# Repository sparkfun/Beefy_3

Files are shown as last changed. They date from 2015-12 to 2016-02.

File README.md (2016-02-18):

SparkFun FTDI Basic Breakout Board-3.3V
========================================

SparkFun Beefy 3 (3.3V FTDI Breakout)

[*SparkFun Beefy 3 (3.3V FTDI Breakout) (DEV-13746)*](https://www.sparkfun.com/products/13746)

This is a breakout board for the FTDI FT232RL USB to serial IC with integrated 3.3V (up to 600mA) regulator to power your project.
The pinout of this board matches the FTDI cable to work with official Arduino and cloned 3.3V Arduino boards.

Repository Contents
-------------------
* **/Hardware** &mdash; All Eagle design files (.brd, .sch)
* **/Production** &mdash; Test bed files and production panel files

Product Versions
----------------
* 
[This](https://www.sparkfun.com/products/13746) &mdash; Higher power 3.3V FTDI Breakout.
* [DEV-09873](https://www.sparkfun.com/products/9873) &mdash; 3.3V FTDI Basic Breakout.
* [DEV-09716](https://www.sparkfun.com/products/9716) &mdash; 5V FTDI Basic Breakout

License Information
-------------------
The hardware is released under [Creative Commons ShareAlike 4.0 International](https://creativecommons.org/licenses/by-sa/4.0/).

Distributed as-is; no warranty is given.

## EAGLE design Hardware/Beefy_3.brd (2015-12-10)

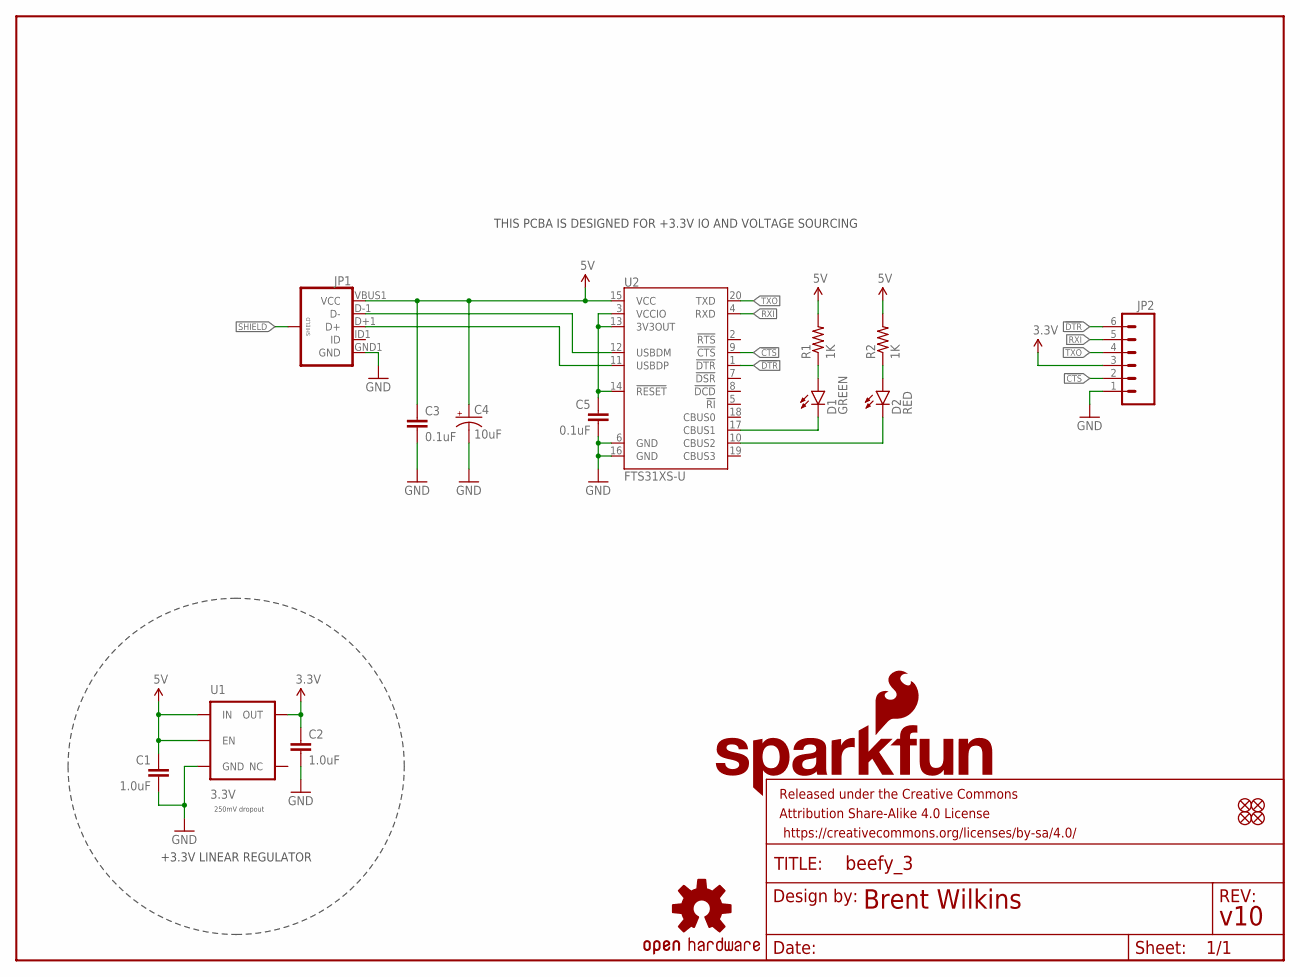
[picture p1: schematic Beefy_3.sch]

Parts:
C1, C2: 1.0uF; 0603-CAP
C3, C5: 0.1uF; 0603-CAP
C4: 10uF; EIA3216
D1: GREEN; LED-0603
D2: RED; LED-0603
FRAME1: FRAME-LETTER; CREATIVE_COMMONS
JP1: USB_MICROB_PLUGCONN-11752; USB-B-MICRO-SMD_V03
JP2: M06SMD-FEMALE-V2; 1X06-SMD-FEMALE-V2
JP3, JP4, JP5, JP6: FIDUCIAL1X2; FIDUCIAL-1X2
LOGO1: OSHW-LOGOS; OSHW-LOGO-S
LOGO2: SFE_LOGO_NAME.1_INCH; SFE_LOGO_NAME_.1
LOGO3: SFE_LOGO_FLAME.1_INCH; SFE_LOGO_FLAME_.1
R1, R2: 1K; 0603-RES
U1: 3.3V; SOT23-5
U2: FTS31XS-U; SSOP20_L

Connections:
3V3: C2.1, JP2.3, U1.5 (OUT)
3V3LC: C5.1, U2.3 (VCCIO), U2.13 (3V3OUT), U2.14 (!RESET)
5V: C1.1, C3.1, C4.A (+), JP1.VBUS1 (VCC), R1.2, R2.2, U1.1 (IN), U1.3 (EN), U2.15 (VCC)
!CTS: JP2.2, U2.9 (!CTS)
!DTR: JP2.6, U2.1 (!DTR)
GND: C1.2, C2.2, C3.2, C4.C (-), C5.2, JP1.GND1 (GND), JP2.1, U1.2 (GND), U2.6 (GND), U2.16 (GND)
unnamed: D2.A, R2.1
unnamed: D1.A, R1.1
RXI: JP2.5, U2.4 (RXD)
RXLED: D1.C, U2.17 (CBUS1)
SHIELD: JP1.SHIELD1 (SHIELD), JP1.SHIELD2 (SHIELD), JP1.SHIELD3 (SHIELD)
TXLED: D2.C, U2.10 (CBUS2)
TXO: JP2.4, U2.20 (TXD)
USB_D+: JP1.D+1 (D+), U2.11 (USBDP)
USB_D-: JP1.D-1 (D-), U2.12 (USBDM)

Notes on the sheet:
+3.3V LINEAR REGULATOR
250mV dropout
THIS PCBA IS DESIGNED FOR +3.3V IO AND VOLTAGE SOURCING

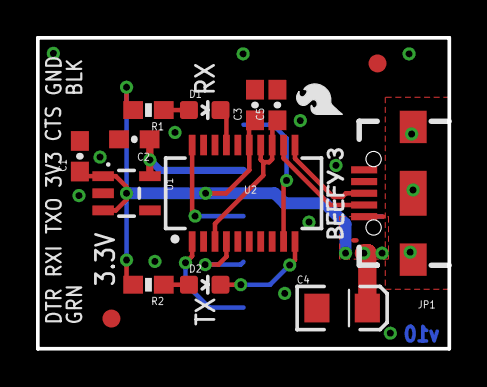
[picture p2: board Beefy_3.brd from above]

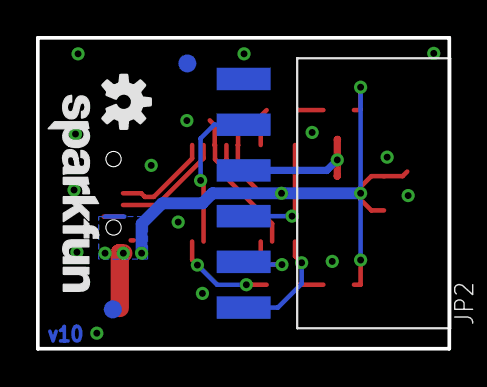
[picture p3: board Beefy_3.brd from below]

Board: 2 copper layers, 22.9 x 17.3 mm, 21 parts (5 on the bottom side), 15 nets.

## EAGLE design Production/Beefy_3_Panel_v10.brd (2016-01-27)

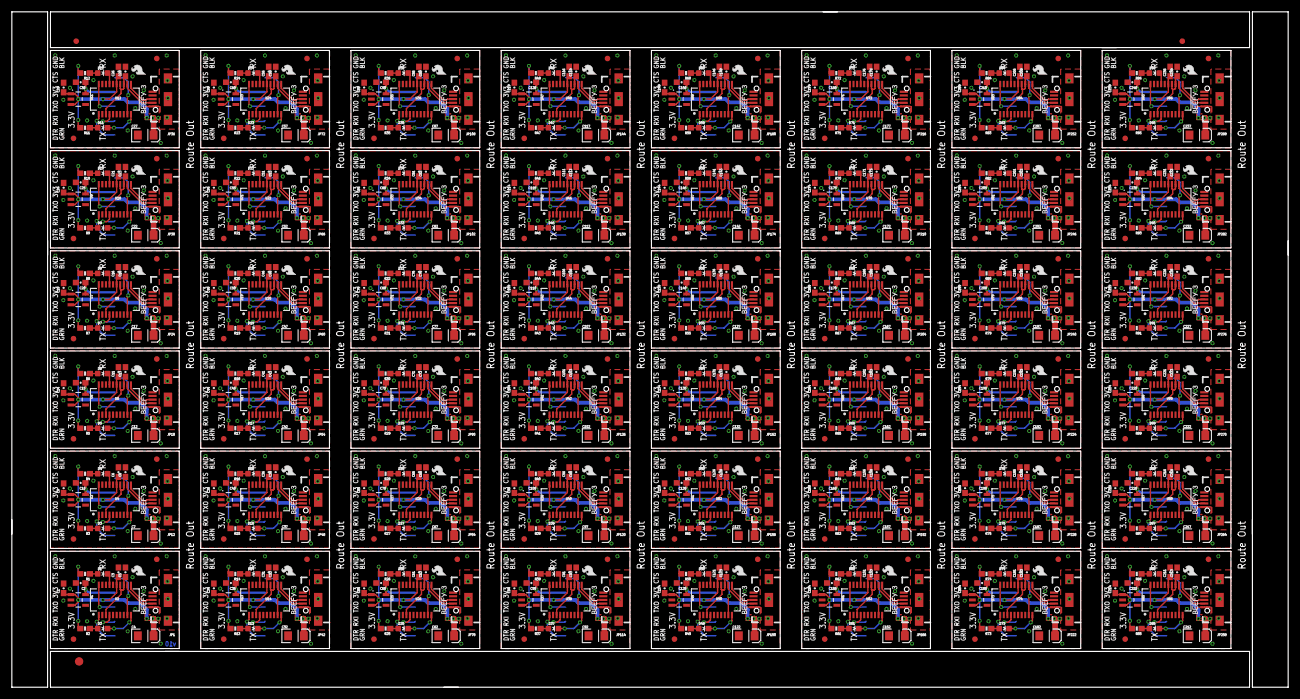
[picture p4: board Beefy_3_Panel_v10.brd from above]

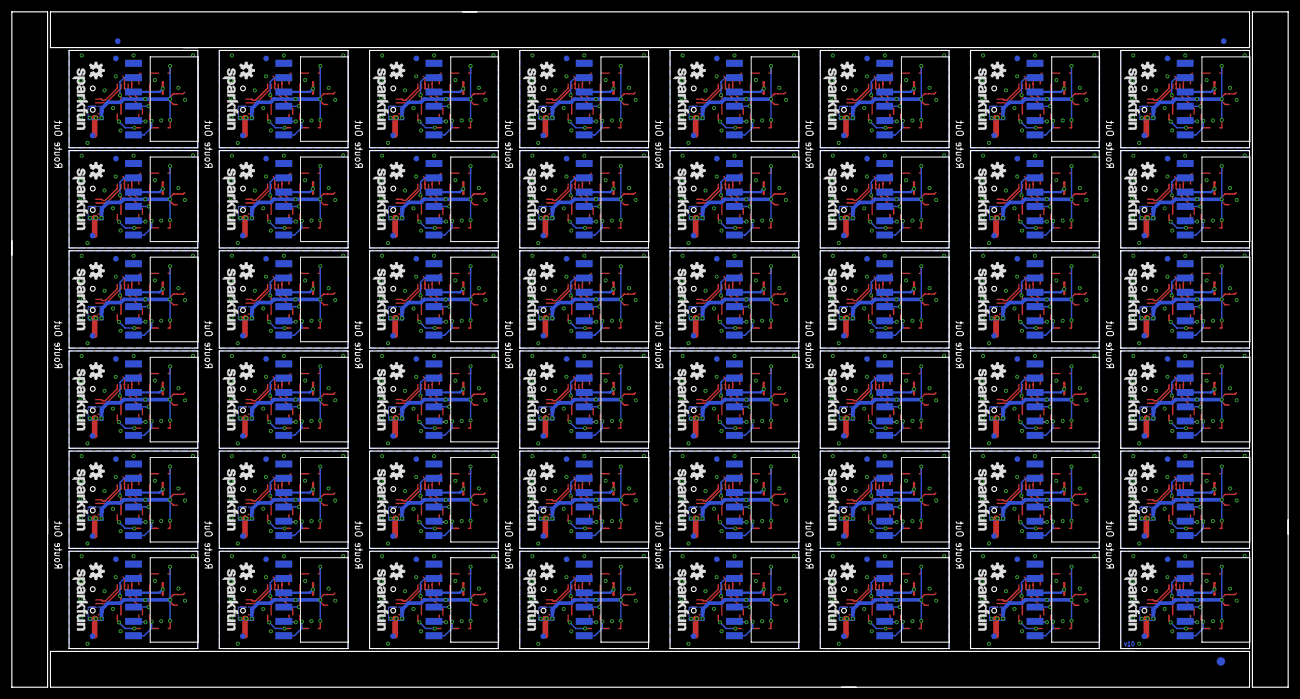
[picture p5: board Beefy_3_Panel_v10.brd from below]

Board: 2 copper layers, 226.6 x 119.9 mm, 966 parts (243 on the bottom side), 720 nets.

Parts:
C1, C2, C9, C10, C14, C15, C19, C20, C24, C25, C29, C30, C34, C35, C39, C40, C44, C45, C49, C50, C54, C55, C59, C60, C64, C65, C69, C70, C74, C75, C79, C80, C84, C85, C89, C90, C94, C95, C99, C100, C104, C105, C109, C110, C114, C115, C119, C120, C124, C125, C129, C130, C134, C135, C139, C140, C144, C145, C149, C150, C154, C155, C159, C160, C164, C165, C169, C170, C174, C175, C179, C180, C184, C185, C189, C190, C194, C195, C199, C200, C204, C205, C209, C210, C214, C215, C219, C220, C224, C225, C229, C230, C234, C235, C239, C240: 1.0uF; 0603-CAP
C3, C5, C6, C8, C11, C13, C16, C18, C21, C23, C26, C28, C31, C33, C36, C38, C41, C43, C46, C48, C51, C53, C56, C58, C61, C63, C66, C68, C71, C73, C76, C78, C81, C83, C86, C88, C91, C93, C96, C98, C101, C103, C106, C108, C111, C113, C116, C118, C121, C123, C126, C128, C131, C133, C136, C138, C141, C143, C146, C148, C151, C153, C156, C158, C161, C163, C166, C168, C171, C173, C176, C178, C181, C183, C186, C188, C191, C193, C196, C198, C201, C203, C206, C208, C211, C213, C216, C218, C221, C223, C226, C228, C231, C233, C236, C238: 0.1uF; 0603-CAP
C4, C7, C12, C17, C22, C27, C32, C37, C42, C47, C52, C57, C62, C67, C72, C77, C82, C87, C92, C97, C102, C107, C112, C117, C122, C127, C132, C137, C142, C147, C152, C157, C162, C167, C172, C177, C182, C187, C192, C197, C202, C207, C212, C217, C222, C227, C232, C237: 10uF; EIA3216
D1, D4, D6, D8, D10, D12, D14, D16, D18, D20, D22, D24, D26, D28, D30, D32, D34, D36, D38, D40, D42, D44, D46, D48, D50, D52, D54, D56, D58, D60, D62, D64, D66, D68, D70, D72, D74, D76, D78, D80, D82, D84, D86, D88, D90, D92, D94, D96: GREEN; LED-0603
D2, D3, D5, D7, D9, D11, D13, D15, D17, D19, D21, D23, D25, D27, D29, D31, D33, D35, D37, D39, D41, D43, D45, D47, D49, D51, D53, D55, D57, D59, D61, D63, D65, D67, D69, D71, D73, D75, D77, D79, D81, D83, D85, D87, D89, D91, D93, D95: RED; LED-0603
E$1, E$2: FIDUCIAL-1.5X3
E$3, E$4, E$7, E$8: FIDUCIAL-1X2
JP1, JP12, JP18, JP24, JP30, JP36, JP42, JP48, JP54, JP60, JP66, JP72, JP78, JP84, JP90, JP96, JP102, JP108, JP114, JP120, JP126, JP132, JP138, JP144, JP150, JP156, JP162, JP168, JP174, JP180, JP186, JP192, JP198, JP204, JP210, JP216, JP222, JP228, JP234, JP240, JP246, JP252, JP258, JP264, JP270, JP276, JP282, JP288: USB-B-MICRO-SMD_V03
JP2, JP7, JP13, JP19, JP25, JP31, JP37, JP43, JP49, JP55, JP61, JP67, JP73, JP79, JP85, JP91, JP97, JP103, JP109, JP115, JP121, JP127, JP133, JP139, JP145, JP151, JP157, JP163, JP169, JP175, JP181, JP187, JP193, JP199, JP205, JP211, JP217, JP223, JP229, JP235, JP241, JP247, JP253, JP259, JP265, JP271, JP277, JP283: 1X06-SMD-FEMALE-V2
JP3, JP4, JP5, JP6, JP8, JP9, JP10, JP11, JP14, JP15, JP16, JP17, JP20, JP21, JP22, JP23, JP26, JP27, JP28, JP29, JP32, JP33, JP34, JP35, JP38, JP39, JP40, JP41, JP44, JP45, JP46, JP47, JP50, JP51, JP52, JP53, JP56, JP57, JP58, JP59, JP62, JP63, JP64, JP65, JP68, JP69, JP70, JP71, JP74, JP75, JP76, JP77, JP80, JP81, JP82, JP83, JP86, JP87, JP88, JP89, JP92, JP93, JP94, JP95, JP98, JP99, JP100, JP101, JP104, JP105, JP106, JP107, JP110, JP111, JP112, JP113, JP116, JP117, JP118, JP119, JP122, JP123, JP124, JP125, JP128, JP129, JP130, JP131, JP134, JP135, JP136, JP137, JP140, JP141, JP142, JP143, JP146, JP147, JP148, JP149, JP152, JP153, JP154, JP155, JP158, JP159, JP160, JP161, JP164, JP165, JP166, JP167, JP170, JP171, JP172, JP173, JP176, JP177, JP178, JP179, JP182, JP183, JP184, JP185, JP188, JP189, JP190, JP191, JP194, JP195, JP196, JP197, JP200, JP201, JP202, JP203, JP206, JP207, JP208, JP209, JP212, JP213, JP214, JP215, JP218, JP219, JP220, JP221, JP224, JP225, JP226, JP227, JP230, JP231, JP232, JP233, JP236, JP237, JP238, JP239, JP242, JP243, JP244, JP245, JP248, JP249, JP250, JP251, JP254, JP255, JP256, JP257, JP260, JP261, JP262, JP263, JP266, JP267, JP268, JP269, JP272, JP273, JP274, JP275, JP278, JP279, JP280, JP281, JP284, JP285, JP286, JP287: FIDUCIAL1X2; FIDUCIAL-1X2
LOGO1, LOGO5, LOGO8, LOGO11, LOGO14, LOGO17, LOGO20, LOGO23, LOGO26, LOGO29, LOGO32, LOGO35, LOGO38, LOGO41, LOGO44, LOGO47, LOGO50, LOGO53, LOGO56, LOGO59, LOGO62, LOGO65, LOGO68, LOGO71, LOGO74, LOGO77, LOGO80, LOGO83, LOGO86, LOGO89, LOGO92, LOGO95, LOGO98, LOGO101, LOGO104, LOGO107, LOGO110, LOGO113, LOGO116, LOGO119, LOGO122, LOGO125, LOGO128, LOGO131, LOGO134, LOGO137, LOGO140, LOGO143: OSHW-LOGOS; OSHW-LOGO-S
LOGO2, LOGO4, LOGO7, LOGO10, LOGO13, LOGO16, LOGO19, LOGO22, LOGO25, LOGO28, LOGO31, LOGO34, LOGO37, LOGO40, LOGO43, LOGO46, LOGO49, LOGO52, LOGO55, LOGO58, LOGO61, LOGO64, LOGO67, LOGO70, LOGO73, LOGO76, LOGO79, LOGO82, LOGO85, LOGO88, LOGO91, LOGO94, LOGO97, LOGO100, LOGO103, LOGO106, LOGO109, LOGO112, LOGO115, LOGO118, LOGO121, LOGO124, LOGO127, LOGO130, LOGO133, LOGO136, LOGO139, LOGO142: SFE_LOGO_NAME.1_INCH; SFE_LOGO_NAME_.1
LOGO3, LOGO6, LOGO9, LOGO12, LOGO15, LOGO18, LOGO21, LOGO24, LOGO27, LOGO30, LOGO33, LOGO36, LOGO39, LOGO42, LOGO45, LOGO48, LOGO51, LOGO54, LOGO57, LOGO60, LOGO63, LOGO66, LOGO69, LOGO72, LOGO75, LOGO78, LOGO81, LOGO84, LOGO87, LOGO90, LOGO93, LOGO96, LOGO99, LOGO102, LOGO105, LOGO108, LOGO111, LOGO114, LOGO117, LOGO120, LOGO123, LOGO126, LOGO129, LOGO132, LOGO135, LOGO138, LOGO141, LOGO144: SFE_LOGO_FLAME.1_INCH; SFE_LOGO_FLAME_.1
R1, R2, R3, R4, R5, R6, R7, R8, R9, R10, R11, R12, R13, R14, R15, R16, R17, R18, R19, R20, R21, R22, R23, R24, R25, R26, R27, R28, R29, R30, R31, R32, R33, R34, R35, R36, R37, R38, R39, R40, R41, R42, R43, R44, R45, R46, R47, R48, R49, R50, R51, R52, R53, R54, R55, R56, R57, R58, R59, R60, R61, R62, R63, R64, R65, R66, R67, R68, R69, R70, R71, R72, R73, R74, R75, R76, R77, R78, R79, R80, R81, R82, R83, R84, R85, R86, R87, R88, R89, R90, R91, R92, R93, R94, R95, R96: 1K; 0603-RES
U1, U3, U5, U7, U9, U11, U13, U15, U17, U19, U21, U23, U25, U27, U29, U31, U33, U35, U37, U39, U41, U43, U45, U47, U49, U51, U53, U55, U57, U59, U61, U63, U65, U67, U69, U71, U73, U75, U77, U79, U81, U83, U85, U87, U89, U91, U93, U95: 3.3V; SOT23-5
U2, U4, U6, U8, U10, U12, U14, U16, U18, U20, U22, U24, U26, U28, U30, U32, U34, U36, U38, U40, U42, U44, U46, U48, U50, U52, U54, U56, U58, U60, U62, U64, U66, U68, U70, U72, U74, U76, U78, U80, U82, U84, U86, U88, U90, U92, U94, U96: FTS31XS-U; SSOP20_L

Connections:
3V1: C10.1, JP7.3, U3.5
3V2: C15.1, JP13.3, U5.5
3V3: C2.1, JP2.3, U1.5
3V3LC: C5.1, U2.3, U2.13, U2.14
3V3LC1: C8.1, U4.3, U4.13, U4.14
3V3LC2: C13.1, U6.3, U6.13, U6.14
3V3LC3: C18.1, U8.3, U8.13, U8.14
3V3LC4: C23.1, U10.3, U10.13, U10.14
3V3LC5: C28.1, U12.3, U12.13, U12.14
3V3LC6: C33.1, U14.3, U14.13, U14.14
3V3LC7: C38.1, U16.3, U16.13, U16.14
3V3LC8: C43.1, U18.3, U18.13, U18.14
3V3LC9: C48.1, U20.3, U20.13, U20.14
3V3LC10: C53.1, U22.3, U22.13, U22.14
3V3LC11: C58.1, U24.3, U24.13, U24.14
3V3LC12: C63.1, U26.3, U26.13, U26.14
3V3LC13: C68.1, U28.3, U28.13, U28.14
3V3LC14: C73.1, U30.3, U30.13, U30.14
3V3LC15: C78.1, U32.3, U32.13, U32.14
3V3LC16: C83.1, U34.3, U34.13, U34.14
3V3LC17: C88.1, U36.3, U36.13, U36.14
3V3LC18: C93.1, U38.3, U38.13, U38.14
3V3LC19: C98.1, U40.3, U40.13, U40.14
3V3LC20: C103.1, U42.3, U42.13, U42.14
3V3LC21: C108.1, U44.3, U44.13, U44.14
3V3LC22: C113.1, U46.3, U46.13, U46.14
3V3LC23: C118.1, U48.3, U48.13, U48.14
3V3LC24: C123.1, U50.3, U50.13, U50.14
3V3LC25: C128.1, U52.3, U52.13, U52.14
3V3LC26: C133.1, U54.3, U54.13, U54.14
3V3LC27: C138.1, U56.3, U56.13, U56.14
3V3LC28: C143.1, U58.3, U58.13, U58.14
3V3LC29: C148.1, U60.3, U60.13, U60.14
3V3LC30: C153.1, U62.3, U62.13, U62.14
3V3LC31: C158.1, U64.3, U64.13, U64.14
3V3LC32: C163.1, U66.3, U66.13, U66.14
3V3LC33: C168.1, U68.3, U68.13, U68.14
3V3LC34: C173.1, U70.3, U70.13, U70.14
3V3LC35: C178.1, U72.3, U72.13, U72.14
3V3LC36: C183.1, U74.3, U74.13, U74.14
3V3LC37: C188.1, U76.3, U76.13, U76.14
3V3LC38: C193.1, U78.3, U78.13, U78.14
3V3LC39: C198.1, U80.3, U80.13, U80.14
3V3LC40: C203.1, U82.3, U82.13, U82.14
3V3LC41: C208.1, U84.3, U84.13, U84.14
3V3LC42: C213.1, U86.3, U86.13, U86.14
3V3LC43: C218.1, U88.3, U88.13, U88.14
3V3LC44: C223.1, U90.3, U90.13, U90.14
3V3LC45: C228.1, U92.3, U92.13, U92.14
3V3LC46: C233.1, U94.3, U94.13, U94.14
3V3LC47: C238.1, U96.3, U96.13, U96.14
3V4: C20.1, JP19.3, U7.5
3V5: C25.1, JP25.3, U9.5
3V6: C30.1, JP31.3, U11.5
3V7: C35.1, JP37.3, U13.5
3V8: C40.1, JP43.3, U15.5
3V9: C45.1, JP49.3, U17.5
3V10: C50.1, JP55.3, U19.5
3V11: C55.1, JP61.3, U21.5
3V12: C60.1, JP67.3, U23.5
3V13: C65.1, JP73.3, U25.5
3V14: C70.1, JP79.3, U27.5
3V15: C75.1, JP85.3, U29.5
3V16: C80.1, JP91.3, U31.5
3V17: C85.1, JP97.3, U33.5
3V18: C90.1, JP103.3, U35.5
3V19: C95.1, JP109.3, U37.5
3V20: C100.1, JP115.3, U39.5
3V21: C105.1, JP121.3, U41.5
3V22: C110.1, JP127.3, U43.5
3V23: C115.1, JP133.3, U45.5
3V24: C120.1, JP139.3, U47.5
3V25: C125.1, JP145.3, U49.5
3V26: C130.1, JP151.3, U51.5
3V27: C135.1, JP157.3, U53.5
3V28: C140.1, JP163.3, U55.5
3V29: C145.1, JP169.3, U57.5
3V30: C150.1, JP175.3, U59.5
3V31: C155.1, JP181.3, U61.5
3V32: C160.1, JP187.3, U63.5
3V33: C165.1, JP193.3, U65.5
3V34: C170.1, JP199.3, U67.5
3V35: C175.1, JP205.3, U69.5
3V36: C180.1, JP211.3, U71.5
3V37: C185.1, JP217.3, U73.5
3V38: C190.1, JP223.3, U75.5
3V39: C195.1, JP229.3, U77.5
3V40: C200.1, JP235.3, U79.5
3V41: C205.1, JP241.3, U81.5
3V42: C210.1, JP247.3, U83.5
3V43: C215.1, JP253.3, U85.5
3V44: C220.1, JP259.3, U87.5
3V45: C225.1, JP265.3, U89.5
3V46: C230.1, JP271.3, U91.5
3V47: C235.1, JP277.3, U93.5
3V48: C240.1, JP283.3, U95.5
5V: C1.1, C3.1, C4.A, JP1.VBUS1, R1.2, R2.2, U1.1, U1.3, U2.15
5V1: C6.1, C7.A, C9.1, JP12.VBUS1, R3.2, R4.2, U3.1, U3.3, U4.15
5V2: C11.1, C12.A, C14.1, JP18.VBUS1, R5.2, R6.2, U5.1, U5.3, U6.15
5V3: C16.1, C17.A, C19.1, JP24.VBUS1, R7.2, R8.2, U7.1, U7.3, U8.15
5V4: C21.1, C22.A, C24.1, JP30.VBUS1, R9.2, R10.2, U9.1, U9.3, U10.15
5V5: C26.1, C27.A, C29.1, JP36.VBUS1, R11.2, R12.2, U11.1, U11.3, U12.15
5V6: C31.1, C32.A, C34.1, JP42.VBUS1, R13.2, R14.2, U13.1, U13.3, U14.15
5V7: C36.1, C37.A, C39.1, JP48.VBUS1, R15.2, R16.2, U15.1, U15.3, U16.15
5V8: C41.1, C42.A, C44.1, JP54.VBUS1, R17.2, R18.2, U17.1, U17.3, U18.15
5V9: C46.1, C47.A, C49.1, JP60.VBUS1, R19.2, R20.2, U19.1, U19.3, U20.15
5V10: C51.1, C52.A, C54.1, JP66.VBUS1, R21.2, R22.2, U21.1, U21.3, U22.15
5V11: C56.1, C57.A, C59.1, JP72.VBUS1, R23.2, R24.2, U23.1, U23.3, U24.15
5V12: C61.1, C62.A, C64.1, JP78.VBUS1, R25.2, R26.2, U25.1, U25.3, U26.15
5V13: C66.1, C67.A, C69.1, JP84.VBUS1, R27.2, R28.2, U27.1, U27.3, U28.15
5V14: C71.1, C72.A, C74.1, JP90.VBUS1, R29.2, R30.2, U29.1, U29.3, U30.15
5V15: C76.1, C77.A, C79.1, JP96.VBUS1, R31.2, R32.2, U31.1, U31.3, U32.15
5V16: C81.1, C82.A, C84.1, JP102.VBUS1, R33.2, R34.2, U33.1, U33.3, U34.15
5V17: C86.1, C87.A, C89.1, JP108.VBUS1, R35.2, R36.2, U35.1, U35.3, U36.15
5V18: C91.1, C92.A, C94.1, JP114.VBUS1, R37.2, R38.2, U37.1, U37.3, U38.15
5V19: C96.1, C97.A, C99.1, JP120.VBUS1, R39.2, R40.2, U39.1, U39.3, U40.15
5V20: C101.1, C102.A, C104.1, JP126.VBUS1, R41.2, R42.2, U41.1, U41.3, U42.15
5V21: C106.1, C107.A, C109.1, JP132.VBUS1, R43.2, R44.2, U43.1, U43.3, U44.15
5V22: C111.1, C112.A, C114.1, JP138.VBUS1, R45.2, R46.2, U45.1, U45.3, U46.15
5V23: C116.1, C117.A, C119.1, JP144.VBUS1, R47.2, R48.2, U47.1, U47.3, U48.15
5V24: C121.1, C122.A, C124.1, JP150.VBUS1, R49.2, R50.2, U49.1, U49.3, U50.15
5V25: C126.1, C127.A, C129.1, JP156.VBUS1, R51.2, R52.2, U51.1, U51.3, U52.15
5V26: C131.1, C132.A, C134.1, JP162.VBUS1, R53.2, R54.2, U53.1, U53.3, U54.15
5V27: C136.1, C137.A, C139.1, JP168.VBUS1, R55.2, R56.2, U55.1, U55.3, U56.15
5V28: C141.1, C142.A, C144.1, JP174.VBUS1, R57.2, R58.2, U57.1, U57.3, U58.15
5V29: C146.1, C147.A, C149.1, JP180.VBUS1, R59.2, R60.2, U59.1, U59.3, U60.15
5V30: C151.1, C152.A, C154.1, JP186.VBUS1, R61.2, R62.2, U61.1, U61.3, U62.15
5V31: C156.1, C157.A, C159.1, JP192.VBUS1, R63.2, R64.2, U63.1, U63.3, U64.15
5V32: C161.1, C162.A, C164.1, JP198.VBUS1, R65.2, R66.2, U65.1, U65.3, U66.15
5V33: C166.1, C167.A, C169.1, JP204.VBUS1, R67.2, R68.2, U67.1, U67.3, U68.15
5V34: C171.1, C172.A, C174.1, JP210.VBUS1, R69.2, R70.2, U69.1, U69.3, U70.15
5V35: C176.1, C177.A, C179.1, JP216.VBUS1, R71.2, R72.2, U71.1, U71.3, U72.15
5V36: C181.1, C182.A, C184.1, JP222.VBUS1, R73.2, R74.2, U73.1, U73.3, U74.15
5V37: C186.1, C187.A, C189.1, JP228.VBUS1, R75.2, R76.2, U75.1, U75.3, U76.15
5V38: C191.1, C192.A, C194.1, JP234.VBUS1, R77.2, R78.2, U77.1, U77.3, U78.15
5V39: C196.1, C197.A, C199.1, JP240.VBUS1, R79.2, R80.2, U79.1, U79.3, U80.15
5V40: C201.1, C202.A, C204.1, JP246.VBUS1, R81.2, R82.2, U81.1, U81.3, U82.15
5V41: C206.1, C207.A, C209.1, JP252.VBUS1, R83.2, R84.2, U83.1, U83.3, U84.15
5V42: C211.1, C212.A, C214.1, JP258.VBUS1, R85.2, R86.2, U85.1, U85.3, U86.15
5V43: C216.1, C217.A, C219.1, JP264.VBUS1, R87.2, R88.2, U87.1, U87.3, U88.15
5V44: C221.1, C222.A, C224.1, JP270.VBUS1, R89.2, R90.2, U89.1, U89.3, U90.15
5V45: C226.1, C227.A, C229.1, JP276.VBUS1, R91.2, R92.2, U91.1, U91.3, U92.15
5V46: C231.1, C232.A, C234.1, JP282.VBUS1, R93.2, R94.2, U93.1, U93.3, U94.15
5V47: C236.1, C237.A, C239.1, JP288.VBUS1, R95.2, R96.2, U95.1, U95.3, U96.15
!CTS: JP2.2, U2.9
!CTS1: JP7.2, U4.9
!CTS2: JP13.2, U6.9
!CTS3: JP19.2, U8.9
!CTS4: JP25.2, U10.9
!CTS5: JP31.2, U12.9
!CTS6: JP37.2, U14.9
!CTS7: JP43.2, U16.9
!CTS8: JP49.2, U18.9
!CTS9: JP55.2, U20.9
!CTS10: JP61.2, U22.9
!CTS11: JP67.2, U24.9
!CTS12: JP73.2, U26.9
!CTS13: JP79.2, U28.9
!CTS14: JP85.2, U30.9
!CTS15: JP91.2, U32.9
!CTS16: JP97.2, U34.9
!CTS17: JP103.2, U36.9
!CTS18: JP109.2, U38.9
!CTS19: JP115.2, U40.9
!CTS20: JP121.2, U42.9
!CTS21: JP127.2, U44.9
!CTS22: JP133.2, U46.9
!CTS23: JP139.2, U48.9
!CTS24: JP145.2, U50.9
!CTS25: JP151.2, U52.9
!CTS26: JP157.2, U54.9
!CTS27: JP163.2, U56.9
!CTS28: JP169.2, U58.9
!CTS29: JP175.2, U60.9
!CTS30: JP181.2, U62.9
!CTS31: JP187.2, U64.9
!CTS32: JP193.2, U66.9
!CTS33: JP199.2, U68.9
!CTS34: JP205.2, U70.9
!CTS35: JP211.2, U72.9
!CTS36: JP217.2, U74.9
!CTS37: JP223.2, U76.9
!CTS38: JP229.2, U78.9
!CTS39: JP235.2, U80.9
!CTS40: JP241.2, U82.9
!CTS41: JP247.2, U84.9
!CTS42: JP253.2, U86.9
!CTS43: JP259.2, U88.9
!CTS44: JP265.2, U90.9
!CTS45: JP271.2, U92.9
!CTS46: JP277.2, U94.9
!CTS47: JP283.2, U96.9
!DTR: JP2.6, U2.1
!DTR1: JP7.6, U4.1
!DTR2: JP13.6, U6.1
!DTR3: JP19.6, U8.1
!DTR4: JP25.6, U10.1
!DTR5: JP31.6, U12.1
!DTR6: JP37.6, U14.1
!DTR7: JP43.6, U16.1
!DTR8: JP49.6, U18.1
!DTR9: JP55.6, U20.1
!DTR10: JP61.6, U22.1
!DTR11: JP67.6, U24.1
!DTR12: JP73.6, U26.1
!DTR13: JP79.6, U28.1
!DTR14: JP85.6, U30.1
!DTR15: JP91.6, U32.1
!DTR16: JP97.6, U34.1
!DTR17: JP103.6, U36.1
!DTR18: JP109.6, U38.1
!DTR19: JP115.6, U40.1
!DTR20: JP121.6, U42.1
!DTR21: JP127.6, U44.1
!DTR22: JP133.6, U46.1
!DTR23: JP139.6, U48.1
!DTR24: JP145.6, U50.1
!DTR25: JP151.6, U52.1
!DTR26: JP157.6, U54.1
!DTR27: JP163.6, U56.1
!DTR28: JP169.6, U58.1
!DTR29: JP175.6, U60.1
!DTR30: JP181.6, U62.1
!DTR31: JP187.6, U64.1
!DTR32: JP193.6, U66.1
!DTR33: JP199.6, U68.1
!DTR34: JP205.6, U70.1
!DTR35: JP211.6, U72.1
!DTR36: JP217.6, U74.1
!DTR37: JP223.6, U76.1
!DTR38: JP229.6, U78.1
!DTR39: JP235.6, U80.1
!DTR40: JP241.6, U82.1
!DTR41: JP247.6, U84.1
!DTR42: JP253.6, U86.1
!DTR43: JP259.6, U88.1
!DTR44: JP265.6, U90.1
!DTR45: JP271.6, U92.1
!DTR46: JP277.6, U94.1
!DTR47: JP283.6, U96.1
GND: C1.2, C2.2, C3.2, C4.C, C5.2, JP1.GND1, JP2.1, U1.2, U2.6, U2.16
GND1: C6.2, C7.C, C8.2, C9.2, C10.2, JP7.1, JP12.GND1, U3.2, U4.6, U4.16
GND2: C11.2, C12.C, C13.2, C14.2, C15.2, JP13.1, JP18.GND1, U5.2, U6.6, U6.16
GND3: C16.2, C17.C, C18.2, C19.2, C20.2, JP19.1, JP24.GND1, U7.2, U8.6, U8.16
GND4: C21.2, C22.C, C23.2, C24.2, C25.2, JP25.1, JP30.GND1, U9.2, U10.6, U10.16
GND5: C26.2, C27.C, C28.2, C29.2, C30.2, JP31.1, JP36.GND1, U11.2, U12.6, U12.16
GND6: C31.2, C32.C, C33.2, C34.2, C35.2, JP37.1, JP42.GND1, U13.2, U14.6, U14.16
GND7: C36.2, C37.C, C38.2, C39.2, C40.2, JP43.1, JP48.GND1, U15.2, U16.6, U16.16
GND8: C41.2, C42.C, C43.2, C44.2, C45.2, JP49.1, JP54.GND1, U17.2, U18.6, U18.16
GND9: C46.2, C47.C, C48.2, C49.2, C50.2, JP55.1, JP60.GND1, U19.2, U20.6, U20.16
GND10: C51.2, C52.C, C53.2, C54.2, C55.2, JP61.1, JP66.GND1, U21.2, U22.6, U22.16
GND11: C56.2, C57.C, C58.2, C59.2, C60.2, JP67.1, JP72.GND1, U23.2, U24.6, U24.16
GND12: C61.2, C62.C, C63.2, C64.2, C65.2, JP73.1, JP78.GND1, U25.2, U26.6, U26.16
GND13: C66.2, C67.C, C68.2, C69.2, C70.2, JP79.1, JP84.GND1, U27.2, U28.6, U28.16
GND14: C71.2, C72.C, C73.2, C74.2, C75.2, JP85.1, JP90.GND1, U29.2, U30.6, U30.16
GND15: C76.2, C77.C, C78.2, C79.2, C80.2, JP91.1, JP96.GND1, U31.2, U32.6, U32.16
GND16: C81.2, C82.C, C83.2, C84.2, C85.2, JP97.1, JP102.GND1, U33.2, U34.6, U34.16
GND17: C86.2, C87.C, C88.2, C89.2, C90.2, JP103.1, JP108.GND1, U35.2, U36.6, U36.16
GND18: C91.2, C92.C, C93.2, C94.2, C95.2, JP109.1, JP114.GND1, U37.2, U38.6, U38.16
GND19: C96.2, C97.C, C98.2, C99.2, C100.2, JP115.1, JP120.GND1, U39.2, U40.6, U40.16
GND20: C101.2, C102.C, C103.2, C104.2, C105.2, JP121.1, JP126.GND1, U41.2, U42.6, U42.16
GND21: C106.2, C107.C, C108.2, C109.2, C110.2, JP127.1, JP132.GND1, U43.2, U44.6, U44.16
GND22: C111.2, C112.C, C113.2, C114.2, C115.2, JP133.1, JP138.GND1, U45.2, U46.6, U46.16
GND23: C116.2, C117.C, C118.2, C119.2, C120.2, JP139.1, JP144.GND1, U47.2, U48.6, U48.16
GND24: C121.2, C122.C, C123.2, C124.2, C125.2, JP145.1, JP150.GND1, U49.2, U50.6, U50.16
GND25: C126.2, C127.C, C128.2, C129.2, C130.2, JP151.1, JP156.GND1, U51.2, U52.6, U52.16
GND26: C131.2, C132.C, C133.2, C134.2, C135.2, JP157.1, JP162.GND1, U53.2, U54.6, U54.16
GND27: C136.2, C137.C, C138.2, C139.2, C140.2, JP163.1, JP168.GND1, U55.2, U56.6, U56.16
GND28: C141.2, C142.C, C143.2, C144.2, C145.2, JP169.1, JP174.GND1, U57.2, U58.6, U58.16
GND29: C146.2, C147.C, C148.2, C149.2, C150.2, JP175.1, JP180.GND1, U59.2, U60.6, U60.16
GND30: C151.2, C152.C, C153.2, C154.2, C155.2, JP181.1, JP186.GND1, U61.2, U62.6, U62.16
GND31: C156.2, C157.C, C158.2, C159.2, C160.2, JP187.1, JP192.GND1, U63.2, U64.6, U64.16
GND32: C161.2, C162.C, C163.2, C164.2, C165.2, JP193.1, JP198.GND1, U65.2, U66.6, U66.16
GND33: C166.2, C167.C, C168.2, C169.2, C170.2, JP199.1, JP204.GND1, U67.2, U68.6, U68.16
GND34: C171.2, C172.C, C173.2, C174.2, C175.2, JP205.1, JP210.GND1, U69.2, U70.6, U70.16
GND35: C176.2, C177.C, C178.2, C179.2, C180.2, JP211.1, JP216.GND1, U71.2, U72.6, U72.16
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

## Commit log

2015-10-13 Improved high-speed differential routing
    [Beefy_3.brd]
2015-10-13 Added PROD_IDs to library parts and updated them
    [Beefy_3.brd, Beefy_3.sch]
2015-10-19 First pass at using micro B & FT231X
    [Beefy_3.brd, Beefy_3.sch]
2015-10-21 New layout
    [Beefy_3.brd, Beefy_3.sch]
2015-10-22 Changed product name font
    [Beefy_3.brd]
2015-10-22 Added 15 mil staking vias
    [Beefy_3.brd]
2015-10-22 Approved 'errors'
    [Beefy_3.brd]
2015-11-25 Updated version number
    [Beefy_3.brd, Beefy_3.sch]
2015-11-25 Added shield pour
    [Beefy_3.brd, Beefy_3.sch]
2015-11-30 Added flame logo to top and clarified schematic note
    [Beefy_3.brd, Beefy_3.sch]
2015-12-10 moved board fids
    [Beefy_3.brd]
2015-12-10 created panel v10
    [Beefy_3_Panel_v10.brd]
2016-01-27 added bottom side panel fiducials
    [Beefy_3_Panel_v10.brd]

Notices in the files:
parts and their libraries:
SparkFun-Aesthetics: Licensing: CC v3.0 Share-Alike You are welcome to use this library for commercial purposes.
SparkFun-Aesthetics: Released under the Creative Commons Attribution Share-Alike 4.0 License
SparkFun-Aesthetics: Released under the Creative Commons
